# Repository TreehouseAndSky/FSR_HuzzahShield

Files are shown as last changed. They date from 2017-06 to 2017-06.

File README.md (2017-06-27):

# FSR_HuzzahShield

The goal of the project is to analyze a persons sitting posture over time & give immediate feedback if the user has been sitting too long, or has adapted a bad sitting position.

To do this we connect a 4x4 Force Sensitive Resistor matrix to an ESP8266 in order to read out and and wirelessly transmit the resistance values over WiFi with the MQTT protocol.

## Sensor Hardware
Contains the eagle files of the project.

## Sensor Software
Firmware to read out the matrix. The ESP8266 is programmed using Arduino for fast prototyping & access to convenient libraries (eg the PubSubClient MQTT library). And because getting the Espressif Toolchain set up has proved to be a real pain. The data is transferred over MQTT to a central broker (I'm using an old Raspberry Pi) where data processing takes place. Which brings us to

## Broker Software
Contains the data processing code on the central hub. Work in progress.
To set up a Raspberry Pi as a MQTT broker, [this](https://www.youtube.com/watch?v=AsDHEDbyLfg) is a great video.

This README was created using [Dillinger](www.dillinger.io).

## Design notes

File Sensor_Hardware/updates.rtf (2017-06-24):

t = ln(2^10/SA) * RTOTAL * CSAMPLE

RTOTAL = 1M + 273k

Cf toevoegen als compensatie

row amp weg (0V)

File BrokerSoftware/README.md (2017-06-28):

# Helpfile for the Broker Software

## Testing (MacOS X)

### install mosquitto

```sh
$ brew install mosquitto
``` 

### install paho-mqtt Python client library

```sh
$ pip install paho-mqtt
``` 

[Official documentation](https://pypi.python.org/pypi/paho-mqtt/1.1)

### run a mosquitto broker (not background)

```sh
$ mosquitto -c /usr/local/etc/mosquitto/mosquitto.conf
``` 

## Deployment (Raspberry Pi)

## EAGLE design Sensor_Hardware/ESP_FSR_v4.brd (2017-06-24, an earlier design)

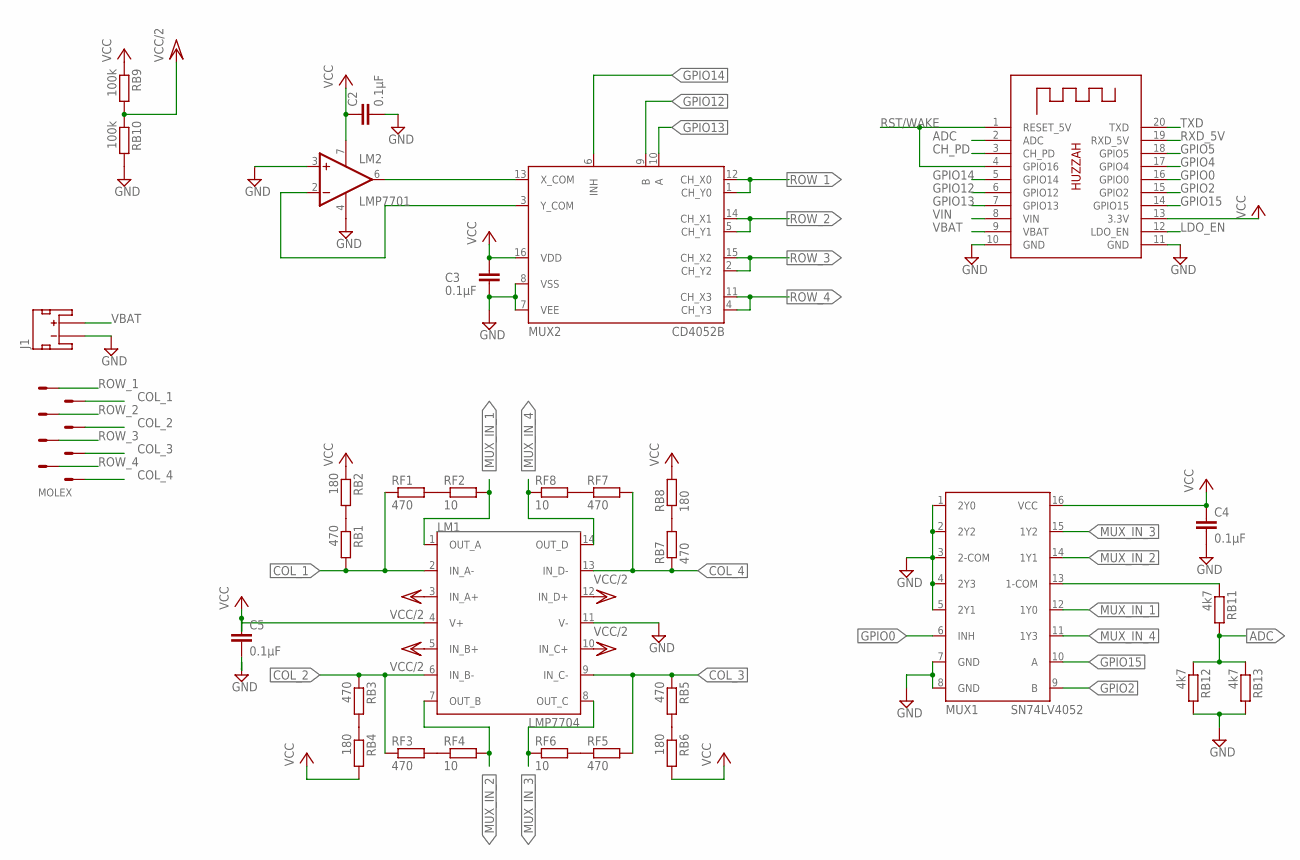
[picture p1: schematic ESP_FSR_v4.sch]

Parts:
C2, C3, C4, C5: 0.1µF; C0805
J1: JST_2MM_MALE; JST-2-SMD
LM1: LMP7704; D_R-PDSO-G14
LM2: LMP7701; D_R-PDSO-G08
MOLEX: 90130-3308
MUX1: SN74LV4052; D_R-PDSO-G16
MUX2: CD4052B; D_R-PDSO-G16
RB1, RB3, RB5, RB7: 470; R0805
RB2, RB4, RB6, RB8: 180; R0805
RB9, RB10: 100k; R0805
RB11, RB12, RB13: 4k7; R0805
RF1, RF3, RF5, RF7: 470; R0805
RF2, RF4, RF6, RF8: 10; R0805
U$1: HUZZAH

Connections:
ADC: RB11.2, RB12.1, RB13.1, U$1.2 (ADC)
CH_PD: U$1.3 (CH_PD)
COL_1: LM1.2 (IN_A-), MOLEX.P$2, RB1.2, RF1.1
COL_2: LM1.6 (IN_B-), MOLEX.P$4, RB3.1, RF3.1
COL_3: LM1.9 (IN_C-), MOLEX.P$6, RB5.1, RF5.2
COL_4: LM1.13 (IN_D-), MOLEX.P$8, RB7.1, RF7.2
GND: C2.2, C3.2, C4.2, C5.2, J1.1 (-), LM1.11 (V-), LM2.3 (+IN), LM2.4 (V-), MUX1.1 (2Y0), MUX1.2 (2Y2), MUX1.3 (2-COM), MUX1.4 (2Y3), MUX1.5 (2Y1), MUX1.7 (GND), MUX1.8 (GND), MUX2.7 (VEE), MUX2.8 (VSS), RB10.2, RB12.2, RB13.2, U$1.10 (GND), U$1.11 (GND)
GPIO0: MUX1.6 (INH), U$1.16 (GPIO0)
GPIO2: MUX1.9 (B), U$1.15 (GPIO2)
GPIO4: U$1.17 (GPIO4)
GPIO5: U$1.18 (GPIO5)
GPIO12: MUX2.9 (B), U$1.6 (GPIO12)
GPIO13: MUX2.10 (A), U$1.7 (GPIO13)
GPIO14: MUX2.6 (INH), U$1.5 (GPIO14)
GPIO15: MUX1.10 (A), U$1.14 (GPIO15)
LDO_EN: U$1.12 (LDO_EN)
MUX_IN_1: LM1.1 (OUT_A), MUX1.12 (1Y0), RF2.2
MUX_IN_2: LM1.7 (OUT_B), MUX1.14 (1Y1), RF4.2
MUX_IN_3: LM1.8 (OUT_C), MUX1.15 (1Y2), RF6.1
MUX_IN_4: LM1.14 (OUT_D), MUX1.11 (1Y3), RF8.1
unnamed: RB3.2, RB4.1
unnamed: RF1.2, RF2.1
unnamed: MUX1.13 (1-COM), RB11.1
unnamed: RF5.1, RF6.2
unnamed: LM2.6 (OUT), MUX2.13 (X_COM)
unnamed: LM2.2 (-IN), MUX2.3 (Y_COM)
unnamed: RF7.1, RF8.2
unnamed: RB5.2, RB6.1
unnamed: RB1.1, RB2.2
unnamed: RF3.2, RF4.1
unnamed: RB7.2, RB8.1
ROW_1: MOLEX.P$1, MUX2.1 (CH_Y0), MUX2.12 (CH_X0)
ROW_2: MOLEX.P$3, MUX2.5 (CH_Y1), MUX2.14 (CH_X1)
ROW_3: MOLEX.P$5, MUX2.2 (CH_Y2), MUX2.15 (CH_X2)
ROW_4: MOLEX.P$7, MUX2.4 (CH_Y3), MUX2.11 (CH_X3)
RST/WAKE: U$1.1 (RESET_5V), U$1.4 (GPIO16)
RXD_5V: U$1.19 (RXD_5V)
TXD: U$1.20 (TXD)
VBAT: J1.2 (+), U$1.9 (VBAT)
VCC: C2.1, C3.1, C4.1, C5.1, LM1.4 (V+), LM2.7 (V+), MUX1.16 (VCC), MUX2.16 (VDD), RB2.1, RB4.2, RB6.2, RB8.2, RB9.1, U$1.13 (3.3V)
VCC/2: LM1.3 (IN_A+), LM1.5 (IN_B+), LM1.10 (IN_C+), LM1.12 (IN_D+), RB9.2, RB10.1
VIN: U$1.8 (VIN)

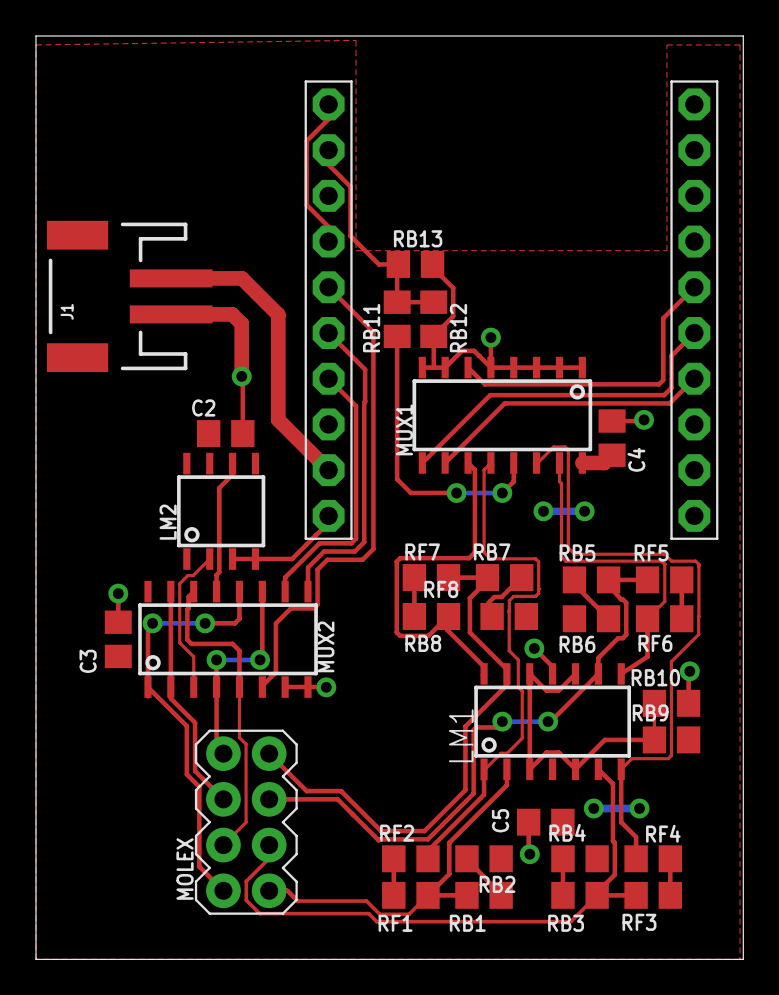
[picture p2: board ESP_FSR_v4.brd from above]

Board: 2 copper layers, 39.3 x 51.3 mm, 32 parts (0 on the bottom side), 35 nets.

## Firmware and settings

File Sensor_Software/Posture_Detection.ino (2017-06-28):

/*
 * Code to run on the ESP8266 posture detection
 * 
 * Requirements
 * 
 * Setup network (Wifi & MQTT)
 * 
 * Switch ROW AMPLIFIERS
 * 
 *    A   - GPIO13
 *    B   - GPIO12
 *    INH - GPIO14
 *    
 *    B   A   INH   OUT
 *    0   0   0     ROW1
 *    0   1   0     ROW2
 *    1   0   0     ROW3
 *    1   1   0     ROW4
 *    X   X   1     NONE
 *-----------------------------------------    
 *
 * Switch ADC MUX
 * 
 *    A   - GPIO15
 *    B   - GPIO2
 *    INH - GPIO0
 *    
 *    B   A   INH   OUT
 *    0   0   0     COLUMN1
 *    0   1   0     COLUMN2
 *    1   0   0     COLUMN3
 *    1   1   0     COLUMN4
 *    X   X   1     NONE
 *-----------------------------------------
 *    
 * Read ADC value
 * 
 * Analyze/(Running) Average result
 * 
 * Loop all sensor points
 * 
 * Transmit
 * 
 * Sleep
 * 
 * 
 */

#include <ESP8266WiFi.h>
#include <PubSubClient.h>
#define DEBUG 1

// Network specific values

const char* ssid = "Telenet_L&K";
const char* password = "Kikikiki01";
const char* mqtt_server = "192.168.0.177";

WiFiClient espClient;
PubSubClient client(espClient);
long lastMsg = 0;
int value = 0;
char* outTopic = "dev/test";
char *inTopic = "inTopic";

const int ROW_APin = 13;
const int ROW_BPin = 12;
const int ROW_INHPin = 14;
const int COL_APin = 15;
const int COL_BPin = 2;
const int COL_INHPin = 0;

int matrix[3][3];

void setup_wifi() {

  delay(10);
  // We start by connecting to a WiFi network
  Serial.println();
  Serial.print("Connecting to ");
  Serial.println(ssid);

  WiFi.begin(ssid, password);

  while (WiFi.status() != WL_CONNECTED) {
    delay(500);
    Serial.print(".");
  }

  randomSeed(micros());

  Serial.println("");
  Serial.println("WiFi connected");
  Serial.println("IP address: ");
  Serial.println(WiFi.localIP());
}



/*
 * Callback function for the MQTT library, this function
 * gets called when a message is published in a topic we subscribed to
 */
void callback(char* topic, byte* payload, unsigned int length) {
  Serial.print("Message arrived [");
  Serial.print(topic);
  Serial.print("] ");
  for (int i = 0; i < length; i++) {
    Serial.print((char)payload[i]);
  }
  Serial.println();

  // Switch on the LED if an 1 was received as first character
  if ((char)payload[0] == '1') {
    digitalWrite(BUILTIN_LED, LOW);   // Turn the LED on (Note that LOW is the voltage level
    // but actually the LED is on; this is because
    // it is acive low on the ESP-01)
  } else {
    digitalWrite(BUILTIN_LED, HIGH);  // Turn the LED off by making the voltage HIGH
  }

}
/*
 * Wifi connection function
 */
void reconnect() {
  // Loop until we're reconnected
  while (!client.connected()) {
    Serial.print("Attempting MQTT connection...");
    // Create a random client ID
    String clientId = "ESP8266Client-";
    clientId += String(random(0xffff), HEX);
    // Attempt to connect
    if (client.connect(clientId.c_str())) {
      Serial.println("connected");
      // Once connected, publish an announcement...
      client.publish(outTopic, "hello world");
      // ... and resubscribe
      client.subscribe(inTopic);
    } else {
      Serial.print("failed, rc=");
      Serial.print(client.state());
      Serial.println(" try again in 5 seconds");
      // Wait 5 seconds before retrying
      delay(5000);
    }
  }
}

/*
 * Switch the row we're measuring on. This drives the row MUX (CD
 */
void switch_row(int row) {
  switch (row) {
    case 0 :
      digitalWrite(ROW_APin, LOW);
      digitalWrite(ROW_BPin, LOW);
      digitalWrite(ROW_INHPin, HIGH);
      break;
      
    case 1 :
      digitalWrite(ROW_APin, LOW);
      digitalWrite(ROW_BPin, LOW);
      digitalWrite(ROW_INHPin, LOW);
      break;
      
    case 2 :
      digitalWrite(ROW_APin, HIGH);
      digitalWrite(ROW_BPin, LOW);
      digitalWrite(ROW_INHPin, LOW);
      break;
      
    case 3 :
      digitalWrite(ROW_APin, LOW);
      digitalWrite(ROW_BPin, HIGH);
      digitalWrite(ROW_INHPin, LOW);
      break;
      
    case 4 :
      digitalWrite(ROW_APin, HIGH);
      digitalWrite(ROW_BPin, HIGH);
      digitalWrite(ROW_INHPin, LOW);
      break;

    default :
      digitalWrite(ROW_APin, LOW);
      digitalWrite(ROW_BPin, LOW);
      digitalWrite(ROW_INHPin, HIGH);
      break;
  }
  
}

void switch_column(int column) {
  switch (column) {
    case 0 :
      digitalWrite(COL_APin, LOW);
      digitalWrite(COL_BPin, LOW);
      digitalWrite(COL_INHPin, HIGH);
      break;
      
    case 1 :
      digitalWrite(COL_APin, LOW);
      digitalWrite(COL_BPin, LOW);
      digitalWrite(COL_INHPin, LOW);
      break;
      
    case 2 :
      digitalWrite(COL_APin, HIGH);
      digitalWrite(COL_BPin, LOW);
      digitalWrite(COL_INHPin, LOW);
      break;
      
    case 3 :
      digitalWrite(COL_APin, LOW);
      digitalWrite(COL_BPin, HIGH);
      digitalWrite(COL_INHPin, LOW);
      break;
      
    case 4 :
      digitalWrite(COL_APin, HIGH);
      digitalWrite(COL_BPin, HIGH);
      digitalWrite(COL_INHPin, LOW);
      break;

    default :
      digitalWrite(COL_APin, LOW);
      digitalWrite(COL_BPin, LOW);
      digitalWrite(COL_INHPin, HIGH);
      break;
  }
  
}

void readPoints() {
  int sensorvalue;
  
  for(int i=0; i<=3; i++) //total delay = 4.(4.(10+4.1)) ms = 64.4ms = 256ms
  {
    switch_row(i);
    for(int j=0; j<=3; j++)
    {
      switch_column(j);
      delay(10); //todo: test settling time;
      sensorvalue = 0;

      //Take an average of 5 analog reads
      for(int k=0; k<5; k++)
      {
        #ifdef DEBUG
        sensorvalue += random(0,1025);
        #else
        sensorvalue += analogRead(A0);
        #endif;
        delay(1);
      };
      
      sensorvalue = sensorvalue/5;
      matrix[i][j] = sensorvalue;
      Serial.print("Element ");
      Serial.print(i);
      Serial.print("x");
      Serial.print(j);
      Serial.print(": ");
      Serial.println(sensorvalue);
    };
  };
  Serial.println("Readout complete");
}

void sendPoints(){
  Serial.println("Sending pressure matrix");
  
//	 Prepare a JSON payload string of format
//	{
//	    "row0":[1001,1002,1003,1004],
//	    "row1":[1005,1006,1007,1008],
//	    "row2":[1009,1010,1011,1012],
//	    "row3":[1013,1014,1015,1016]
//	}
  String payload = "{";
  for(int i=0; i<=3; i++){
      payload += "\"row";
      payload += String(i);
	  payload += "\":[";
      for(int j=0; j<=3; j++){
        payload += String(matrix[i][j]);
        if(j != 3)
          payload += ",";
      };
      payload += "]";
      if (i != 3)
        payload += ",";
  };
  payload += "}";
  
  // Send payload
  char attributes[200];
  payload.toCharArray(attributes, 200);
  client.publish(outTopic, attributes);
  Serial.println(attributes);
}

void setup() {
  pinMode(ROW_APin, OUTPUT);
  pinMode(ROW_BPin, OUTPUT);
  pinMode(ROW_INHPin, OUTPUT);
  pinMode(COL_APin, OUTPUT);
  pinMode(COL_BPin, OUTPUT);
  pinMode(COL_INHPin, OUTPUT);
  switch_row(0);
  switch_column(0);
  pinMode(BUILTIN_LED, OUTPUT);     // Initialize the BUILTIN_LED pin as an output
  Serial.begin(115200);
  setup_wifi();
  client.setServer(mqtt_server, 1883);
  client.setCallback(callback);
}

void loop() {
  
  if (!client.connected()) {
    reconnect();
  }
  client.loop();

  //turn off wifi
  readPoints();

  long now = millis();
  if (now - lastMsg > 5000) {
    //turn on wifi
    lastMsg = now;
    ++value;
    sendPoints();
  }
}

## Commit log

2017-06-09 added Eagle files to the Hardware folder
    [ESP_FSR_v3.brd, ESP_FSR_v3.sch]
2017-06-09 renaming folder
    [ESP_FSR_v3.brd, ESP_FSR_v3.sch]
2017-06-12 Going Arduino
2017-06-24 Adding a few iterations & a to do list
    [ESP_FSR_v4.brd, ESP_FSR_v4.sch, ESP_FSR_v5.brd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]
2017-06-24 Added code to send pressure data over MQTT using JSON syntax
2017-06-28 Update the JSON format the sensor sends

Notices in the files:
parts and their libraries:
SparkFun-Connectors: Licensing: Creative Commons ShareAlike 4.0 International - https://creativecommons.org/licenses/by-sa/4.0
